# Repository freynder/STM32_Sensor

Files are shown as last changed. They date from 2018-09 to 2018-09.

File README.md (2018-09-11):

# STM32 Sensor Node

A Small STM32F103C8T6 board with all functional pins exposed. Similar to the BluePill board except:

- no regulator. Will be powered by 2 AA batteries.
- no USB
- No LED
- No BOOT0/BOOT1 jumper pins. BOOT0 can be pulled high by a button, BOOT1 is pulled low permanently but exposed by a PIN.
- smaller crystals
- RFM69CW + RFM69(H)W + RFM69HCW footprints + u.FL connector
- VBAT can be disconnected from VCC by cutting the solder jumper on the back.

The size is 36.56mm x 20.32mm. 5 mils trace width and clearance. 20 mils edge clearance.

Tested succesfully V3 with jlcpcb order.
Test failed with V3.4 pcbs.io order due to imposed edge clearance. Should be corrected as of V4.3

## Top view
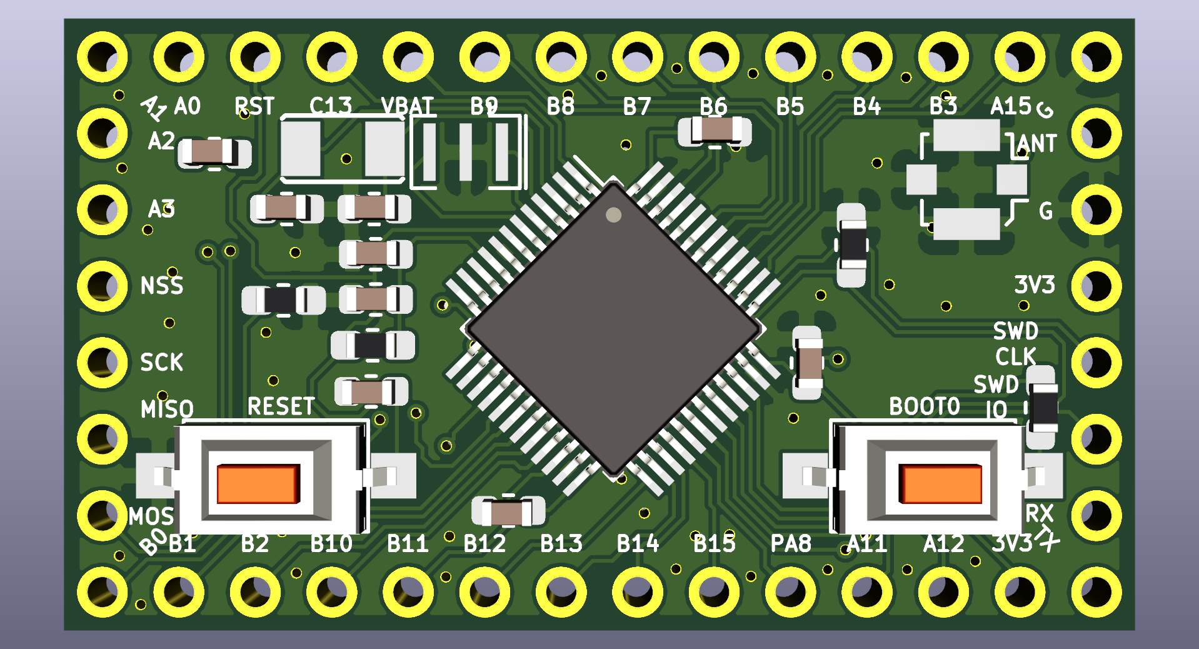
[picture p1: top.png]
Top View Top


## Bottom view
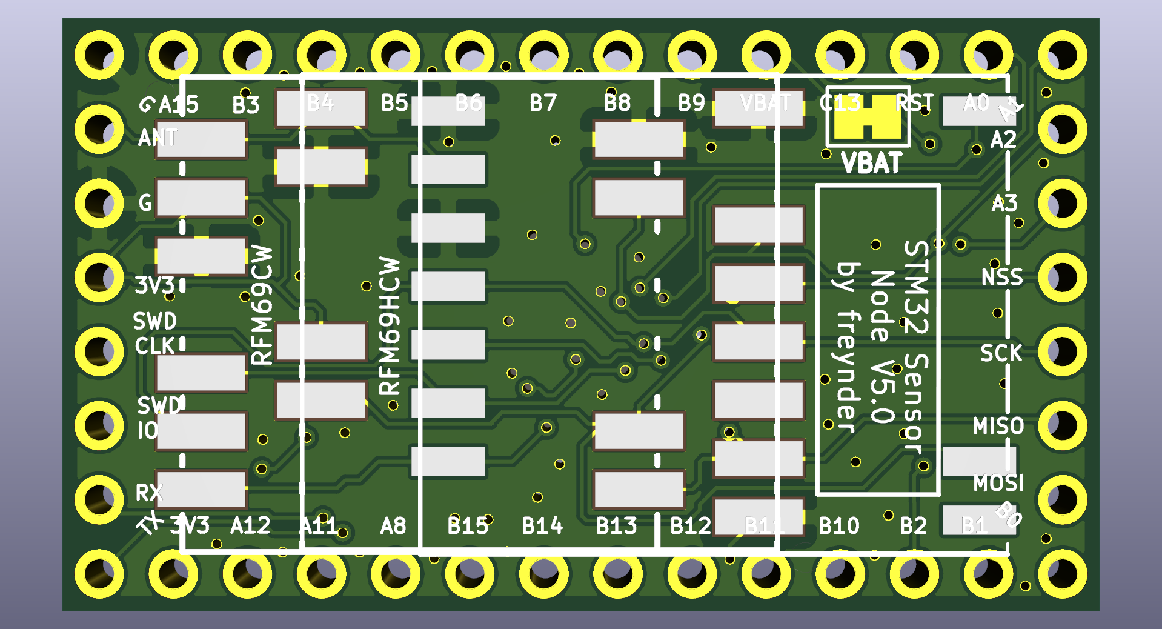
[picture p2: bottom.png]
Bottom View Top


## Version history
- V1: was never released because it was faulty and had less pins exposed.
- V2: had full pin availability but the layout was messy.
- V3: is V2 + u.FL connector + better layout and clearer markings.
- V3.3: corrected mislabeling + moved board edges to fit on breadboard (only sides).
- V3.4: moved labels so they are still visible when headers are soldered on. Optimized a few traces. Changed custom button footprint to RS282G05A3 buttons.
- as of V4 detailed history is tracked in git log.
- V5: Added RFM69(H)W footprints. Cleaned up git. Cleaned up tracks, fab layer, silk screen.

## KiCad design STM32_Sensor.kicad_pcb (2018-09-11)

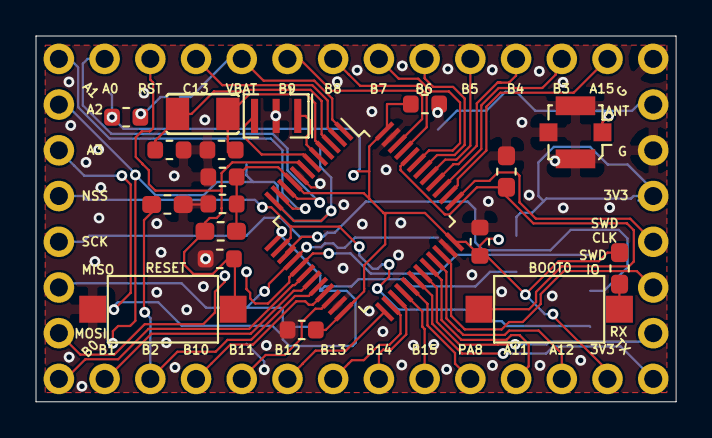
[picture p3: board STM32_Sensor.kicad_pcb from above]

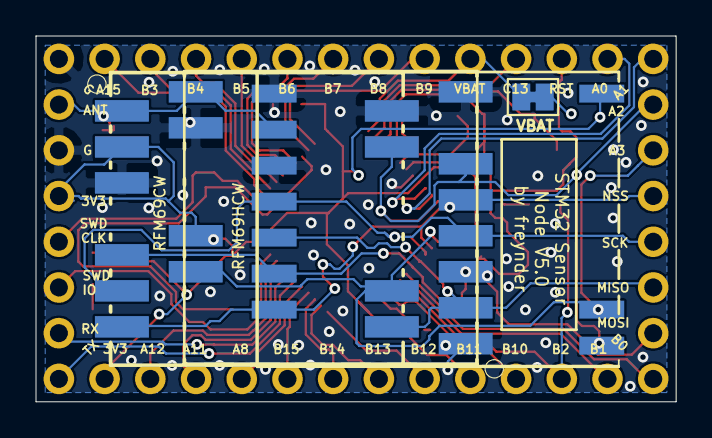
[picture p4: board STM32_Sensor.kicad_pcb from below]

Board: 2 copper layers, 35.6 x 20.3 mm, 27 parts (4 on the bottom side), 45 nets.

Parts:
C1: 1uF; C_0603_1608Metric
C2, C3, C4, C5: 0.1uF; C_0603_1608Metric
C6: 10uF; C_0603_1608Metric
C7: 100nF; C_0603_1608Metric
C8, C9: 10pF; C_0603_1608Metric
J1: Conn Side; PinSocket_1x08_P2.54mm_Vertical_Clear
J2: Conn Down; PinHeader_1x12_P2.54mm_Vertical_Clear
J3: Conn Up; PinHeader_1x12_P2.54mm_Vertical_Clear
J4: Conn Prog; PinSocket_1x08_P2.54mm_Vertical_Clear
J5: u.FL; U.FL_Molex_MCRF_73412-0110_Vertical
JP1: VBAT Jumper; SolderJumper-2_P1.3mm_Bridged_Pad1.0x1.5mm
R1, R2: 10K; R_0603_1608Metric_Pad1.05x0.95mm_HandSolder
R3, R4: 100K; R_0603_1608Metric_Pad1.05x0.95mm_HandSolder
SW1: SW_Reset; SW_SPST_CK_RS282G05A3
SW2: SW_BOOT; SW_SPST_CK_RS282G05A3
U1: STM32F103C8Tx; LQFP-48_7x7mm_P0.5mm
U2: RFM69CW; RFM69CW-XXXS2-MINPADS
U3: RFM69HW; HOPERF_RFM69HW-MINPADS
U4: RFM69HCW; RFM69HCW-XXXS2-MINPADS
Y1: 32768Mhz; Seeedstudio-32kHz_Crystal-FC135
Y2: 8Mhz; Resonator_SMD_muRata_CSTxExxV-3Pin_3.0x1.1mm

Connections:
+3V3: C2.1, C3.1, C4.1, C5.1, C6.1, C7.1, J2.12, J4.4, R1.1, R2.1, U1.9, U1.24, U1.36, U1.48, U2.2, U3.8, U4.13
ANT: J4.2, J5.1, U2.1, U3.10, U4.9
BOOT0: R3.2, SW2.1, U1.44
GND: C1.2, C2.2, C3.2, C4.2, C5.2, C6.2, C8.2, C9.2, J4.1, J4.3, J5.2, R3.1, R4.1, SW1.1, U1.8, U1.23, U1.35, U1.47, U2.3, U2.14, U3.9, U3.11, U4.1, U4.8, U4.10, Y2.2
MISO: J1.6, U1.16, U2.8, U3.13, U4.2
MOSI: J1.7, U1.17, U2.5, U3.14, U4.3
NSS: J1.4, U1.14, U2.7, U3.15, U4.5
unnamed: C7.2, JP1.2
unnamed: R2.2, SW2.2
OSC1: U1.5, Y2.1
OSC2: U1.6, Y2.3
PA0: J3.12, U1.10
PA1: J1.1, U1.11
PA2: J1.2, U1.12, U2.13, U3.1, U4.6
PA3: J1.3, U1.13, U2.9, U3.2, U4.14
PA8: J2.9, U1.29
PA11: J2.10, U1.32
PA12: J2.11, U1.33
PA15: J3.1, U1.38
PB0: J1.8, U1.18
PB1: J2.1, U1.19
PB2: J2.2, R4.2, U1.20
PB3: J3.2, U1.39
PB4: J3.3, U1.40
PB5: J3.4, U1.41
PB6: J3.5, U1.42
PB7: J3.6, U1.43
PB8: J3.7, U1.45
PB9: J3.8, U1.46
PB10: J2.3, U1.21
PB11: J2.4, U1.22
PB12: J2.5, U1.25
PB13: J2.6, U1.26
PB14: J2.7, U1.27
PB15: J2.8, U1.28
PC13: J3.10, U1.2
RST: C1.1, J3.11, R1.2, SW1.2, U1.7
RTCOSC1: C8.1, U1.3, Y1.1
RTCOSC2: C9.1, U1.4, Y1.2
RX: J4.7, U1.31
SCK: J1.5, U1.15, U2.6, U3.12, U4.4
SWDCLK: J4.5, U1.37
SWDIO: J4.6, U1.34
TX: J4.8, U1.30
VBAT: J3.9, JP1.1, U1.1

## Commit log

2018-06-29 Removed oscillator footprint overlap
    [STM32_Sensor_V4-B.Cu.gbl, STM32_Sensor_V4-B.Cu.gbr, STM32_Sensor_V4-B.Fab.gbr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]
2018-07-04 Minor changes to traces
    [STM32_Sensor_V4-B.Cu.gbl, STM32_Sensor_V4-B.Cu.gbr, STM32_Sensor_V4-B.Fab.gbr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]
2018-09-06 Added zones edge clearance
    Added 20 mils clearance between zones and edge to conform to pcbs.io
    manufacturing standards.
    [STM32_Sensor_V4-B.Cu.gbl, STM32_Sensor_V4-B.Cu.gbr, STM32_Sensor_V4-B.Fab.gbr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]
2018-09-07 Updated BOM with links and references
    [STM32_Sensor_V4.csv]
2018-09-10 Added support for RFM69HCW
    Previously only RFM69CW and RFM69(H)W were supported.
    [STM32_Sensor_V4-B.Cu.gbl, STM32_Sensor_V4-B.Cu.gbr, STM32_Sensor_V4-B.Fab.gbr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]
2018-09-10 Optimize fab and silk layer
    [STM32_Sensor_V4.kicad_pcb]
2018-09-11 Cleaned up project
    Removed files that can be generated except for top and bottom
    images which are referenced in the README.md
    [STM32_Sensor.kicad_pcb, STM32_Sensor.sch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]
